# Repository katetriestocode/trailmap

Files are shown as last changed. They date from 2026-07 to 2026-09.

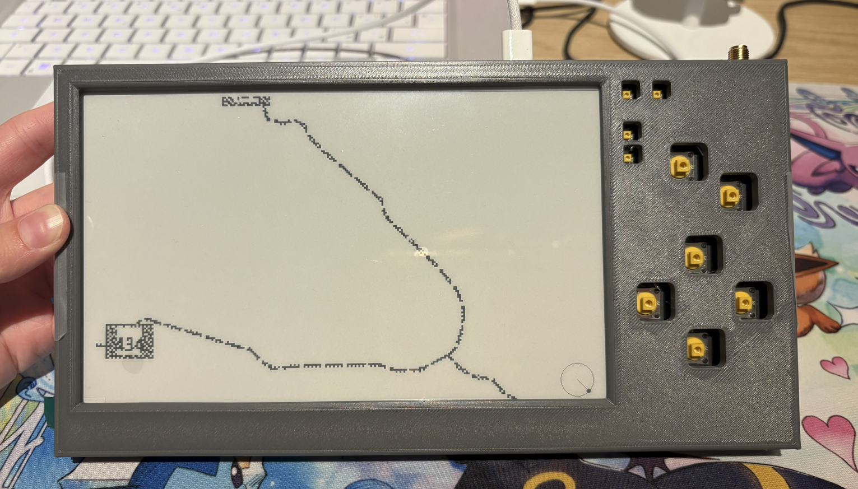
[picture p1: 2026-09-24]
Screenshot 2026-09-24 234755.png

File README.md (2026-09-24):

# trailmap
trailmap is a long lasting, gps enabled, e-ink trail map viewer! equipped with temperature, humidity, magnetometer, altitude and gps, it lets the user choose and follow hiking trails like a map! with a usb-c rechargeable lipo battery, it will provide a long lasting and wifi-scarcity proof solution to digital maps :D

this is the working version! (disclaimer: no antenna as it has not delivered yet, so manual gps coords insertion for now!)



provisional 3d model:

model

pcb:





schematic:

schematic

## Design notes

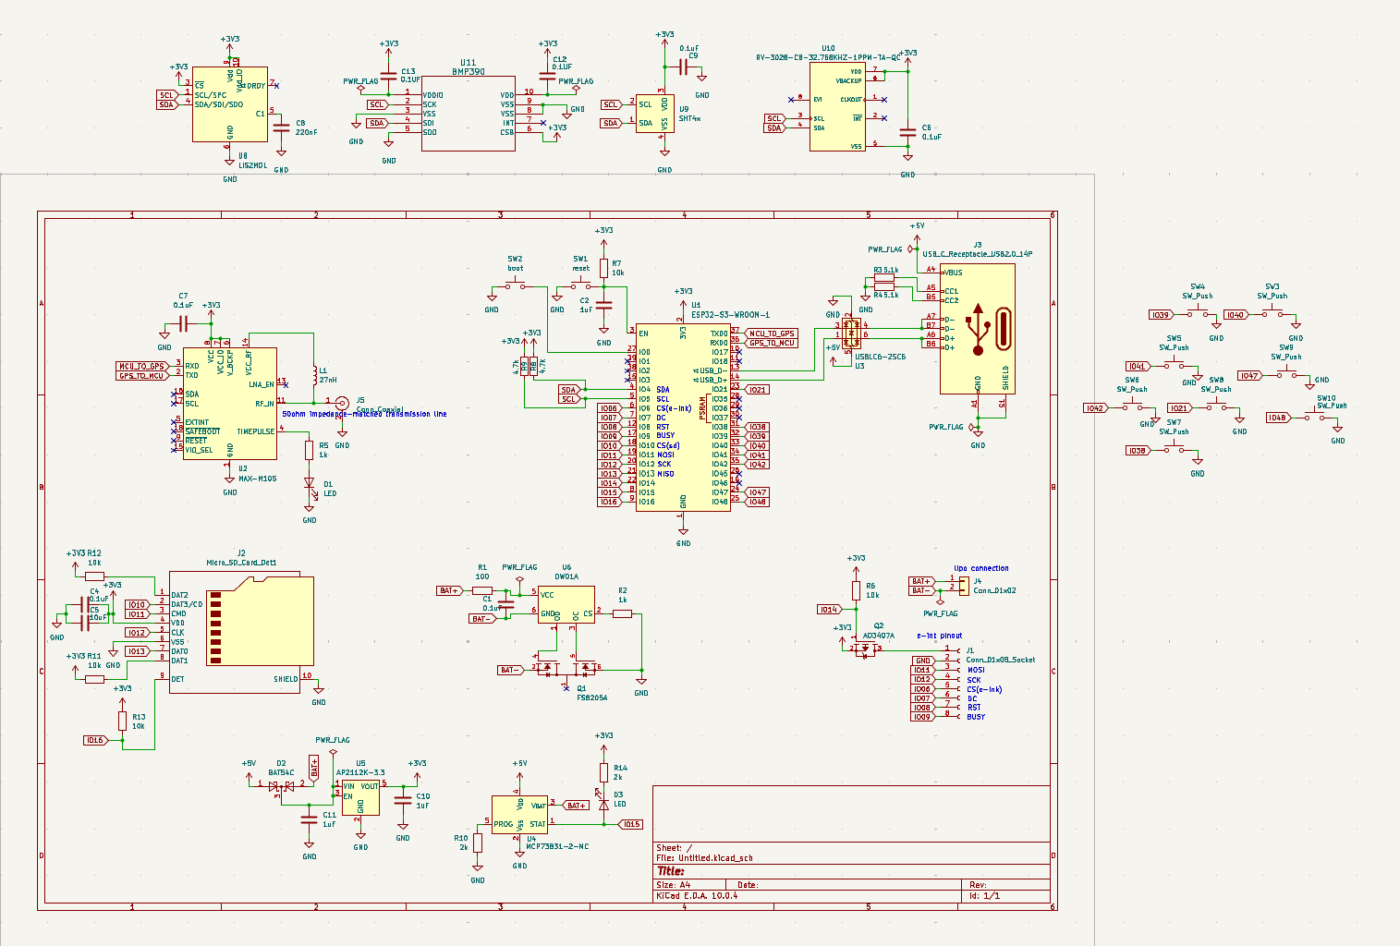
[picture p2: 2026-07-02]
assets/schematic.png

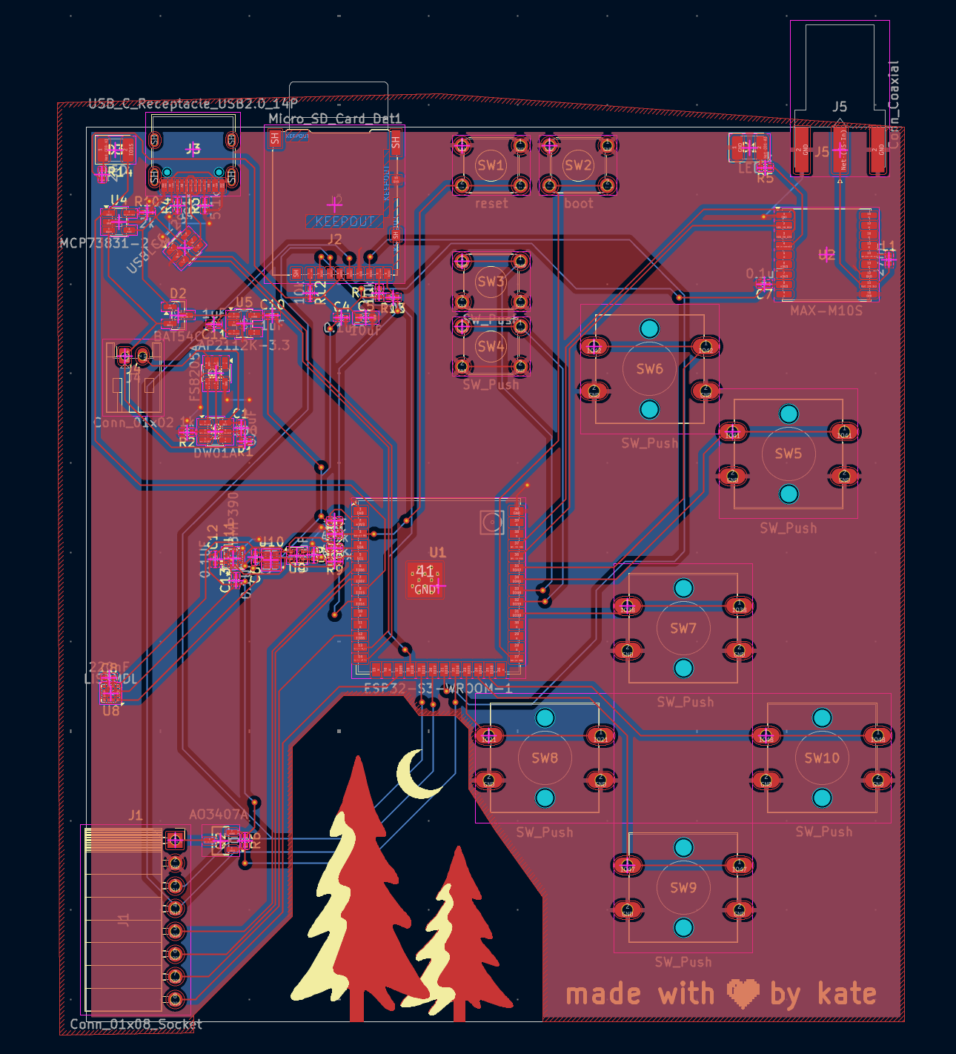
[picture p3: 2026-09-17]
assets/pcb.png

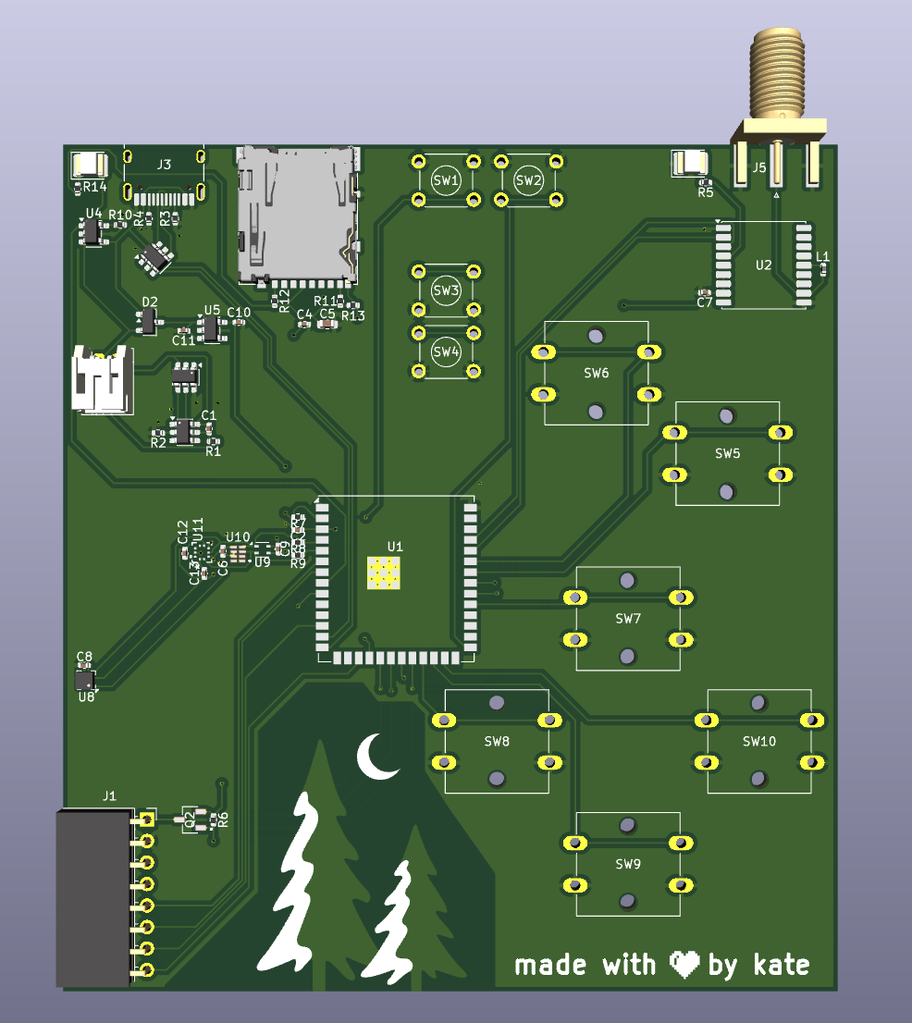
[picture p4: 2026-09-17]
assets/3dpcb.png

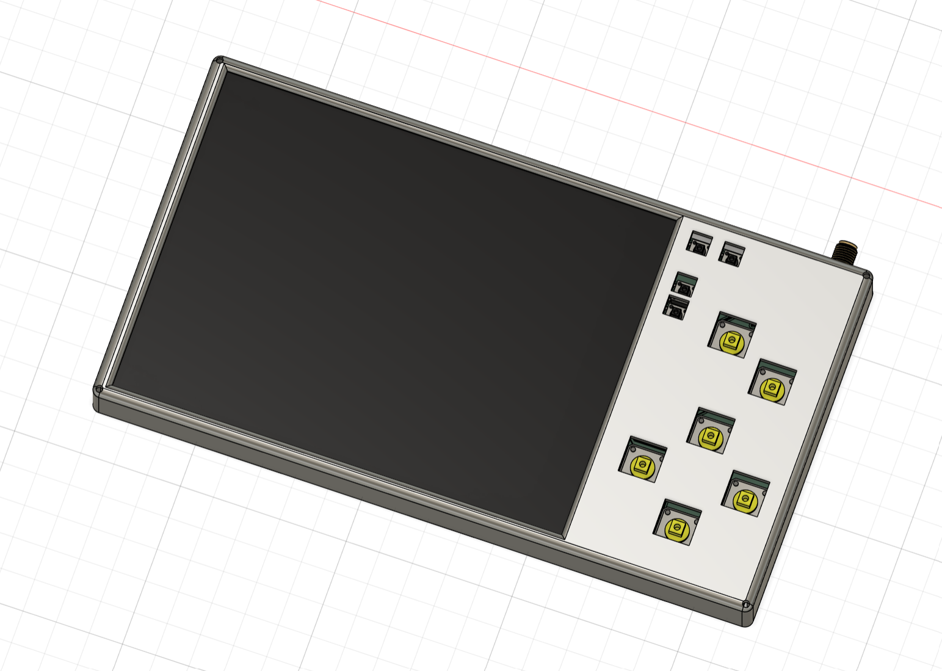
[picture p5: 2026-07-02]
assets/model.png

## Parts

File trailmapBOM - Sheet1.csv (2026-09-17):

item | price | link
PCB | 4$ | JLCPCB
assembly | 139.15$ | JLCPCB
shipping | tba ~10$?
e-ink and adapter | 41$ | https://buy-lcd.com/products/gdey075t7?VariantsId=10628
shipping | 11.42
total: | 196$

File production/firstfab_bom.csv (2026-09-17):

Designator | Footprint | Quantity | Value | LCSC Part #
C1, C12, C13, C14, C4, C7, C9 | 0402 | 7 | 0.1uF
C10, C11, C2 | 0402 | 3 | 1uF
C5 | 0603 | 1 | 10uF
C8 | 0402 | 1 | 220nF
D1, D3 | 1210 | 2 | LED
D2 | SOT-23 | 1 | BAT54C
J1 | PinSocket_1x08_P2.54mm_Horizontal | 1 | Conn_01x08_Socket
J2 | microSD_HC_Hirose_DM3AT-SF-PEJM5 | 1 | Micro_SD_Card_Det1
J3 | USB_C_Receptacle_HRO_TYPE-C-31-M-12 | 1 | USB_C_Receptacle_USB2.0_14P
J4 | JST_PH_S2B-PH-K_1x02_P2.00mm_Horizontal | 1 | Conn_01x02
J5 | SMA_Amphenol_132289_EdgeMount | 1 | Conn_Coaxial
L1 | 0402 | 1 | 27nH
Q1 | SOT-23-6 | 1 | FS8205A
Q2 | SOT95P280X125-3N | 1 | AO3407A
R1 | 0402 | 1 | 100
R10, R14 | 0402 | 2 | 2k
R11, R12, R13, R6, R7 | 0402 | 5 | 10k
R2, R5 | 0402 | 2 | 1k
R3, R4 | 0402 | 2 | 5.1k
R8, R9 | 0402 | 2 | 4.7k
SW1 | SW_TH_Tactile_Omron_B3F-100x | 1 | reset
SW10, SW5, SW6, SW7, SW8, SW9 | SW_SPST_Omron_B3F-40xx | 6 | SW_Push
SW2 | SW_TH_Tactile_Omron_B3F-100x | 1 | boot
SW3, SW4 | SW_TH_Tactile_Omron_B3F-100x | 2 | SW_Push
U1 | ESP32-S3-WROOM-1U | 1 | ESP32-S3-WROOM-1
U11 | 10LGA_2X2X0p75_BOS | 1 | BMP390
U2 | ublox_MAX | 1 | MAX-M10S
U3 | SOT-23-6 | 1 | USBLC6-2SC6
U4 | SOT-23-5 | 1 | MCP73831-2-MC
U5 | SOT-23-5 | 1 | AP2112K-3.3
U6 | SOT-23-6 | 1 | DW01A
U7 | MicroCrystal_C7_SON-8_1.5x3.2mm_P0.9mm | 1 | RV-3028-C7
U8 | LGA-12_2x2mm_P0.5mm | 1 | LIS2MDL
U9 | Sensirion_DFN-4_1.5x1.5mm_P0.8mm_SHT4x_NoCentralPad | 1 | SHT4x

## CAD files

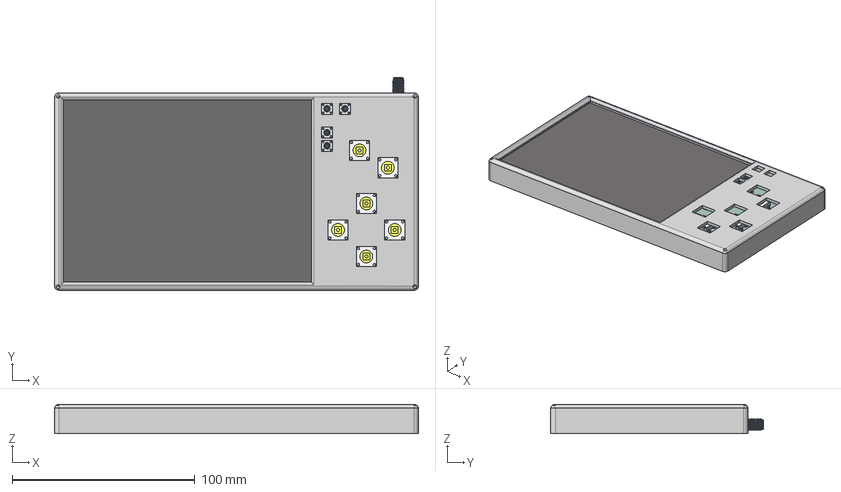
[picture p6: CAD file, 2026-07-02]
3d/caseprototype.step
199.0 x 116.2 x 16.0 mm

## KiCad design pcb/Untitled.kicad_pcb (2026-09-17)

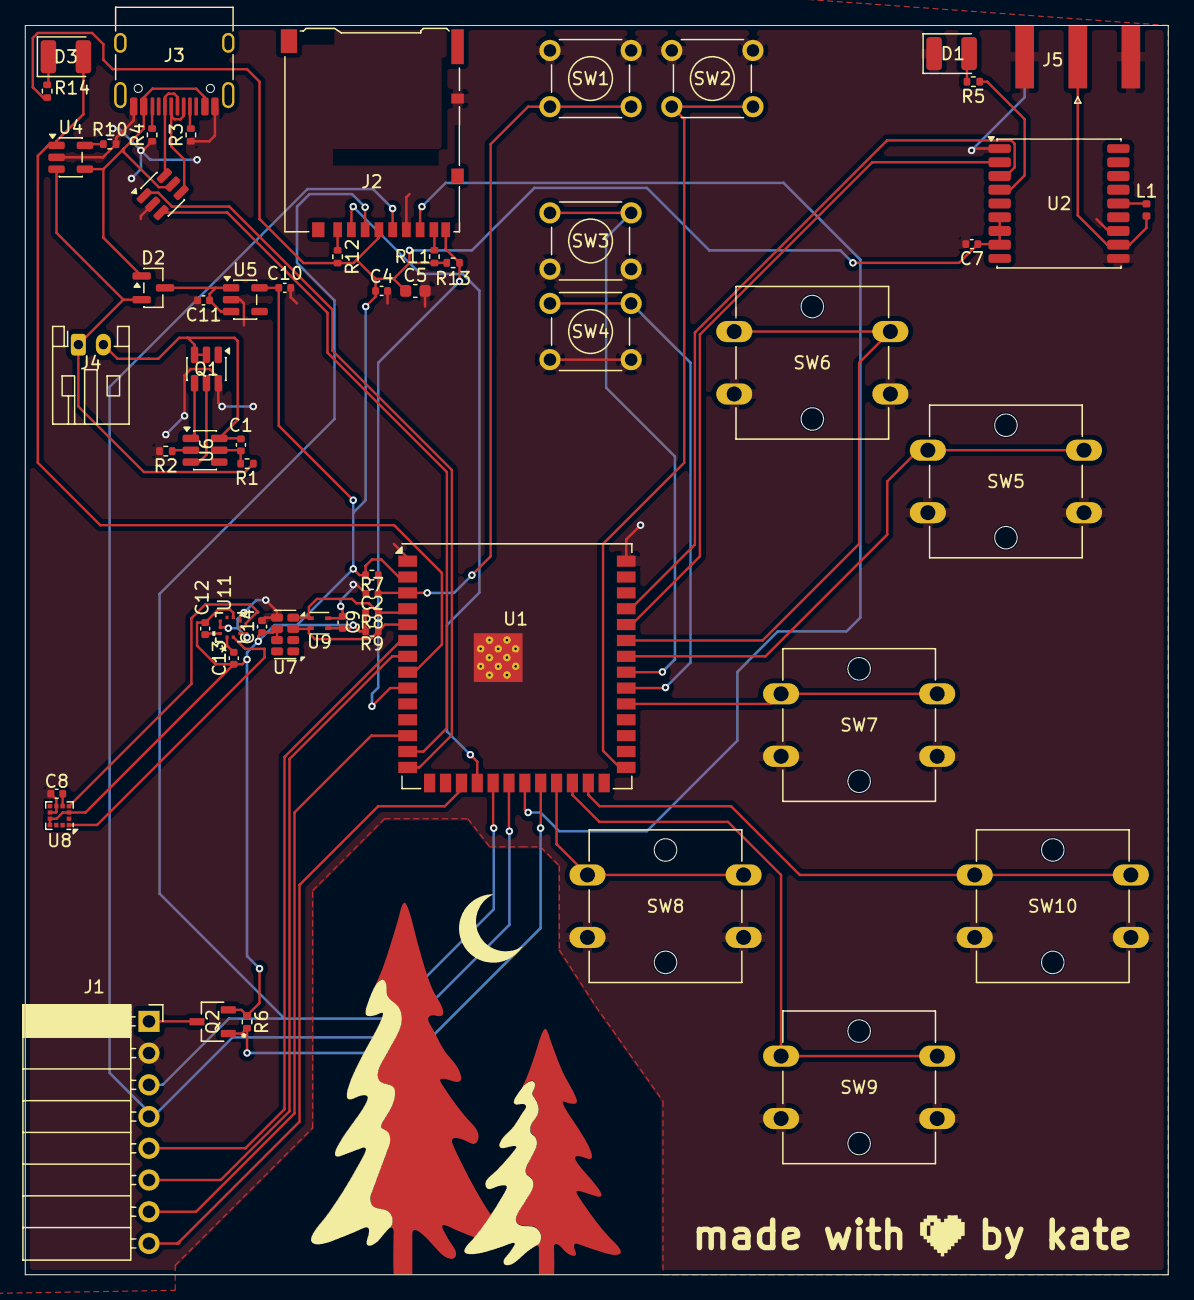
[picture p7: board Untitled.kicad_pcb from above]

Board: 2 copper layers, 91.5 x 100.0 mm, 57 parts (0 on the bottom side), 53 nets.

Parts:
C1, C4, C7, C9, C14: 0.1uF; C_0402_1005Metric
C2, C10, C11: 1uF; C_0402_1005Metric
C5: 10uF; C_0603_1608Metric
C8: 220nF; C_0402_1005Metric
C12, C13: 0.1UF; C_0402_1005Metric
D1, D3: LED; LED_1210_3225Metric
D2: BAT54C; SOT-23
J1: Conn_01x08_Socket; PinSocket_1x08_P2.54mm_Horizontal
J2: Micro_SD_Card_Det1; microSD_HC_Hirose_DM3AT-SF-PEJM5
J3: USB_C_Receptacle_USB2.0_14P; USB_C_Receptacle_HRO_TYPE-C-31-M-12
J4: Conn_01x02; JST_PH_S2B-PH-K_1x02_P2.00mm_Horizontal
J5: Conn_Coaxial; SMA_Amphenol_132289_EdgeMount
L1: 27nH; L_0402_1005Metric
Q1: FS8205A; SOT-23-6
Q2: AO3407A; SOT95P280X125-3N
R1: 100; R_0402_1005Metric
R2, R5: 1k; R_0402_1005Metric
R3, R4: 5.1k; R_0402_1005Metric
R6, R7, R11, R12, R13: 10k; R_0402_1005Metric
R8, R9: 4.7k; R_0402_1005Metric
R10, R14: 2k; R_0402_1005Metric
SW1: reset; SW_TH_Tactile_Omron_B3F-100x
SW2: boot; SW_TH_Tactile_Omron_B3F-100x
SW3, SW4: SW_Push; SW_TH_Tactile_Omron_B3F-100x
SW5, SW6, SW7, SW8, SW9, SW10: SW_Push; SW_SPST_Omron_B3F-40xx
U1: ESP32-S3-WROOM-1; ESP32-S3-WROOM-1U
U2: MAX-M10S; ublox_MAX
U3: USBLC6-2SC6; SOT-23-6
U4: MCP73831-2-MC; SOT-23-5
U5: AP2112K-3.3; SOT-23-5
U6: DW01A; SOT-23-6
U7: RV-3028-C7; MicroCrystal_C7_SON-8_1.5x3.2mm_P0.9mm
U8: LIS2MDL; LGA-12_2x2mm_P0.5mm
U9: SHT4x; Sensirion_DFN-4_1.5x1.5mm_P0.8mm_SHT4x_NoCentralPad
U11: BMP390; 10LGA_2X2X0p75_BOS

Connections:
+3V3: C4.1, C5.1, C7.1, C9.2, C10.1, C12.1, C13.1, C14.1, J2.4 (VDD), Q2.2, R6.1, R7.1, R8.2, R9.2, R11.2, R12.2, R13.1, R14.1, U1.2 (3V3), U2.6 (V_BCKP), U2.7 (VCC_IO), U2.8 (VCC), U5.5 (VOUT), U7.6 (VBACKUP), U7.7 (VDD), U8.3 (~CS), U8.9 (Vdd), U8.10 (Vdd_IO), U9.3 (VDD), U11.6 (CSB)
+5V: D2.1, J3.A4 (VBUS), J3.A9 (VBUS), J3.B4 (VBUS), J3.B9 (VBUS), U3.5 (VBUS), U4.4 (V_{DD})
BAT+: D2.2, J4.1, R1.1, U4.3 (V_{BAT})
BAT-: C1.2, J4.2, Q1.2, Q1.3, U6.6 (GND)
GND: C2.2, C4.2, C5.2, C7.2, C8.2, C9.1, C10.2, C11.2, C14.2, D1.1 (K), J1.2, J2.6 (VSS), J2.10 (SHIELD), J3.A1 (GND), J3.A12 (GND), J3.B1 (GND), J3.B12 (GND), J5.2 (Ext), Q1.6, R2.2, R3.1, R4.1, R10.2, SW1.1, SW2.1, SW3.2, SW4.2, SW5.2, SW6.2, SW7.2, SW8.2, SW9.2, SW10.2, U1.1 (GND), U1.40 (GND), U1.41 (GND), U2.1 (GND), U2.10 (GND), U2.12 (GND), U3.2 (GND), U4.2 (V_{SS}), U5.2 (GND), U7.5 (VSS), U8.6 (GND), U8.8 (GND), U9.4 (VSS), U11.3 (VSS), U11.5 (SDO), U11.8 (VSS), U11.9 (VSS)
GPS_TO_MCU: U1.36 (RXD0), U2.2 (TXD)
IO06: J1.5, U1.6 (IO6)
IO07: J1.6, U1.7 (IO7)
IO08: J1.7, U1.12 (IO8)
IO09: J1.8, U1.17 (IO9)
IO10: J2.2 (DAT3/CD), U1.18 (IO10)
IO11: J1.3, J2.3 (CMD), U1.19 (IO11)
IO12: J1.4, J2.5 (CLK), U1.20 (IO12)
IO13: J2.7 (DAT0), U1.21 (IO13)
IO14: Q2.1, R6.2, U1.22 (IO14)
IO15: D3.2 (A), U1.8 (IO15), U4.1 (STAT)
IO16: J2.9 (DET), R13.2, U1.9 (IO16)
IO21: SW8.1, U1.23 (IO21)
IO38: SW7.1, U1.31 (IO38)
IO39: SW4.1, U1.32 (IO39)
IO40: SW3.1, U1.33 (IO40)
IO41: SW5.1, U1.34 (IO41)
IO42: SW6.1, U1.35 (IO42)
IO47: SW9.1, U1.24 (IO47)
IO48: SW10.1, U1.25 (IO48)
MCU_TO_GPS: U1.37 (TXD0), U2.3 (RXD)
unnamed: D1.2 (A), R5.2
unnamed: D3.1 (K), R14.2
unnamed: J1.1, Q2.3
unnamed: J2.8 (DAT1), R11.1
unnamed: J2.1 (DAT2), R12.1
unnamed: J3.A5 (CC1), R3.2
unnamed: J3.B5 (CC2), R4.2
unnamed: J3.A6 (D+), J3.B6 (D+), U3.6 (I/O1)
unnamed: J3.A7 (D-), J3.B7 (D-), U3.4 (I/O2)
unnamed: J5.1 (In), L1.2, U2.11 (RF_IN)
unnamed: C2.1, R7.2, SW1.2, U1.3 (EN)
unnamed: SW2.2, U1.27 (IO0)
unnamed: U1.14 (USB_D+), U3.1 (I/O1)
unnamed: U1.13 (USB_D-), U3.3 (I/O2)
unnamed: R5.1, U2.4 (TIMEPULSE)
unnamed: L1.1, U2.14 (VCC_RF)
unnamed: R10.1, U4.5 (PROG)
unnamed: C11.1, D2.3, U5.1 (VIN), U5.3 (EN)
unnamed: R2.1, U6.2 (CS)
unnamed: Q1.5, U6.3 (OC)
unnamed: Q1.4, U6.1 (OD)
unnamed: C1.1, R1.2, U6.5 (VCC)
unnamed: C8.1, U8.5 (C1)
unnamed: C12.2, U11.10 (VDD)
unnamed: C13.2, U11.1 (VDDIO)
SCL: R9.1, U1.5 (IO5), U7.3 (SCL), U8.1 (SCL/SPC), U9.2 (SCL), U11.2 (SCK)
SDA: R8.1, U1.4 (IO4), U7.4 (SDA), U8.4 (SDA/SDI/SDO), U9.1 (SDA), U11.4 (SDI)

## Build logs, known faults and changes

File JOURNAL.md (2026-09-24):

# 9/24/2026 7 PM - built!

_Time spent: 5?h_

After ages, i fixed up the code, adapted it to work without gps, made a demo code to test the e-ink, downloaded maps.. etc! anyways it works:


# 7/02/2026 7 PM - bom!

_Time spent: 1h_

I finished the BOM, redone, quite expensive :,) but i couldnt really get it down. I also redid the graphics for my board:


# 7/01/2026 6 PM - 3d model!

_Time spent: 1.5h_

I made a first draft of the 3d model! this is with a provisional eink size, so i might change. tho its a start for submission!


# 7/01/2026 2 PM - pcb finalized!

_Time spent: 2h_

I finished the pcb, and removed all errors but the ones i am ignoring, like pads too small (its the part footprint). 


# 6/30/2026 4 PM - cost reduction!

_Time spent: 1h_

I got the cost down! assembly of only two boards, no standard pieces, and not assembling everything takes it down to around 80$! I also changed the magnetometer to a LIS2MDL, instead of a lis3mdl which i found out is out of production! now i will look at the other pieces i will have to hand solder, as i am unsure how i will solder smd pieces like the esp
{F266392B-B6CA-4F24-A104-2809517627C4}


# 6/28/2026 10 PM - more wiring + first price check!

_Time spent: 1h_

i started wiring other components but the important ones, fixing errors, and establishing a better layout. I checked prices for just boards, and found everything under 100x100mm is so much cheaper than anything slightly above, so i reduced the space to 100mm horizontally and vertically 100mm, which i can easily reduce based on the screen size i will decided. I got a first pcba price estimate from jlcpcb, and it was 250$??? this is cuz theres like more than 100 dollars of various fees because it is standard rather than econ (constraint based on needing the esp32 wroom 1, which isnt in econ :P) i will drastically reduce the price by soldering it myself (maybe with a hot plate?)
(https://lapse.hackclub.com/timelapse/qy0DC-9HV17Z)



# 6/27/2026 7 PM - wiring start!

_Time spent: 2h_

i found out that i need a HAT to connect the e-ink to my board, which is about 8 euros on aliexpress. I then started wiring, being careful to place decouplers near their adjacent part, and wiring the important wires first (eg info parts and battery)
(https://lapse.hackclub.com/timelapse/zSaDSLh_QurV)


# 6/27/2026 1 PM - switches, buttons, e-ink, and layout start!

_Time spent: 2h_

i struggled choosing which buttons to use, but ended up choosing one with an attachment that would allow a custom cap to make the buttons look more professional. I also started laying out the items based on the e-ink layout, considering that the gps should be away from everything else, and that the usb-c and sd card need to be in a convenient position.
(https://lapse.hackclub.com/timelapse/XH70X7rhDU6x)+(https://lapse.hackclub.com/timelapse/bGLBh-pUC-5d)


# 6/26/2026 5 PM - footprint assignment!

_Time spent: 2h_

assigned footprints! i assigned all the various footprints (except buttons) i struggled figuring out what components corresponded to which SOTs :D
(https://lapse.hackclub.com/timelapse/Y9WYruspzZDs)


# 6/26/2026 10 AM - finished schematic!

_Time spent: 3h_

completely finished wiring, with 0 erros now! took ages to find all the needed decoupling and to figure out were pullups were needed, since i am still a beginenr haha. really proud of it so far. i also struggled with pwr_flags since i kept getting erros about them. im gonna start placing the components next!




# 5/21/2026 4 PM - more wiring

_Time spent: 0.5h_

wired the gps module! it was really tricky as i could not find a lot of schematics online, i got it mostly done but had to ask AI how to wire vcc_rf:



i also started wiring the e-ink, and used the ao3407a documentation to wire it :P






# 5/21/2026 8 AM - wiring the battery protection

_Time spent: 1h_

i wired the battery protection, which turned out to be a huge hassle. i was struggling with the documentation until i found this diagram online:



which really helped me wire everything. tho, my 1 pin is floating (together with the 8 since theyre together), and i asked ai what to do, so apparently i should leave a copper 'island' for it in the pcb to act as a heatsink. ill double check this later.

this is what i did, yay!


i also started scheming the usb:



which i also wired the protection, plus the boot and reset switches for the esp :PP





# 5/19/2026 4 PM - found and placed components!

_Time spent: 1h_

so i found the missing symbols and footprints, and loaded everything into kicad. i mapped everything out according to its role:

so it (atm) looks like this:






# 5/12/2026 7 PM - planning and part finding!

_Time spent: 1.5h_

I started by roughly finding all the parts i wanted for the functions!
The functions i plan are:

- [ ] e-ink display
- [ ] live updating map
- [ ] preloaded trail route map
- [ ] live positioning
- [ ] long lasting battery
- [ ] usb-c charging
- [ ] compass
- [ ] altimeter
- [ ] direction pointing
- [ ] clock
- [ ] temperature
- [ ] sensor

Additionally, since this is made for outdoors, i need it to be safe, reliable and durable, so i added all the possible precautions regarding power.



i also started reflecting on the actual screen, but i found that e-ink displays can get really expensive really fast. I provisionally decided on a 5.8" wave-share display, but i need to check regarding partial refresh, as in rapid movements it would be beneficial for it to not repeatedly refresh the whole page.



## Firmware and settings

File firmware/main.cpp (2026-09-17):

#include <Arduino.h>
#include <Wire.h>
#include <SPI.h>
#include <SD.h>
#include <math.h>
#include <HardwareSerial.h>
#include <TinyGPSPlus.h>
#include <Adafruit_Sensor.h>
#include <Adafruit_LIS3MDL.h>
#include <Adafruit_BMP390.h>
#include <Adafruit_SHT4x.h>
#include <GxEPD2_BW.h> 


#define I2C_SDA 4
#define I2C_SCL 5
#define GPS_TX 37
#define GPS_RX 36
#define SD_CS 18
#define EINK_CS 6
#define EINK_DC 7
#define EINK_RST 12
#define EINK_BUSY 17


#define BTN_ZOOM_IN 31
#define BTN_ZOOM_OUT 32
#define BTN_A 47
#define BTN_B 48

#define BTN_UP 41
#define BTN_DOWN 38
#define BTN_LEFT 42
#define BTN_RIGHT 21

HardwareSerial GPSSerial(1);
TinyGPSPlus gps;

Adafruit_LIS3MDL magnetometer;
Adafruit_BMP390 altimeter;
Adafruit_SHT4x sht40;

GxEPD2_BW<x::HEIGHT> display(x(EINK_CS, EINK_DC, EINK_RST, EINK_BUSY));


int currentZoom = 14; 
const int MIN_ZOOM = 10;
const int MAX_ZOOM = 16;


double currentLat = 45.4384;
double currentLon = 10.9916;
float heading = 0.0;
float currentTemp = 0.0;
float currentAlt = 0.0;

bool mapNeedsRefresh = true;


void updateSensors();
void handleButtons();
void drawMapScreen();
void drawBMPFromSD(const char *filename, int16_t x, int16_t y);
void drawCompass(int16_t x, int16_t y, float head);
int long2tilex(double lon, int z);
int lat2tiley(double lat, int z);


void setup() {
  Serial.begin(115200);
  

  Wire.begin(I2C_SDA, I2C_SCL);
  if (!magnetometer.begin_I2C()) Serial.println("LIS3MDL Init Failed!");
  if (!altimeter.begin_I2C()) Serial.println("BMP390 Init Failed!");
  if (!sht40.begin()) Serial.println("SHT40 Init Failed!");


  GPSSerial.begin(9600, SERIAL_8N1, GPS_RX, GPS_TX);


  if (!SD.begin(SD_CS)) Serial.println("SD Card Mount Failed!");


  display.init(115200, true, 2, false); // Init with diagnostic output
  display.setRotation(1); // Landscape
  display.fillScreen(GxEPD_WHITE);
  display.display();


  pinMode(BTN_ZOOM_IN, INPUT_PULLUP);
  pinMode(BTN_ZOOM_OUT, INPUT_PULLUP);
  pinMode(BTN_A, INPUT_PULLUP);
}


void loop() {
  while (GPSSerial.available() > 0) {
    if (gps.encode(GPSSerial.read())) {
      if (gps.location.isUpdated()) {
        currentLat = gps.location.lat();
        currentLon = gps.location.lng();
      }
    }
  }


  updateSensors();


  handleButtons();


  if (mapNeedsRefresh) {
    drawMapScreen();
    mapNeedsRefresh = false;
  }
  
  delay(50);
}


void updateSensors() {
  sensors_event_t event;
  magnetometer.getEvent(&event);
  

  heading = atan2(event.magnetic.y, event.magnetic.x) * 180.0 / M_PI;
  if (heading < 0) heading += 360.0;

  sensors_event_t humidity, temp;
  sht40.getEvent(&humidity, &temp);
  currentTemp = temp.temperature;

  currentAlt = altimeter.readAltitude(1013.25); 
}

void handleButtons() {

  if (digitalRead(BTN_ZOOM_IN) == LOW) {
    if (currentZoom < MAX_ZOOM) {
      currentZoom++;
      mapNeedsRefresh = true;
    }
    delay(300);
  }
  
  if (digitalRead(BTN_ZOOM_OUT) == LOW) {
    if (currentZoom > MIN_ZOOM) {
      currentZoom--;
      mapNeedsRefresh = true;
    }
    delay(300);
  }

  if (digitalRead(BTN_A) == LOW) {
    mapNeedsRefresh = true;
    delay(300);
  }
}


void drawMapScreen() {

  int tileX = long2tilex(currentLon, currentZoom);
  int tileY = lat2tiley(currentLat, currentZoom);


  String filePath = "/" + String(currentZoom) + "/" + String(tileX) + "/" + String(tileY) + ".bmp";
  
  display.setFullWindow();
  display.firstPage();
  do {
    display.fillScreen(GxEPD_WHITE);
    

    drawBMPFromSD(filePath.c_str(), 0, (display.height() - 256) / 2); 


    int uiX = 200;
    display.fillRect(uiX, 0, display.width() - uiX, display.height(), GxEPD_WHITE);
    display.drawRect(uiX, 0, display.width() - uiX, display.height(), GxEPD_BLACK);


    display.setTextColor(GxEPD_BLACK);
    display.setCursor(uiX + 5, 10);
    display.print("Zoom: "); display.print(currentZoom);
    
    display.setCursor(uiX + 5, 30);
    display.print("Alt: "); display.print(currentAlt, 0); display.print("m");
    
    display.setCursor(uiX + 5, 50);
    display.print("Temp: "); display.print(currentTemp, 1); display.print("C");

    // 6. Draw Compass User Indicator
    drawCompass(uiX + 45, 100, heading);

  } while (display.nextPage());
}

void drawCompass(int16_t x, int16_t y, float head) {
  // Draw outer ring
  display.drawCircle(x, y, 15, GxEPD_BLACK);
  

  float rad = (head - 90.0) * (M_PI / 180.0);
  int16_t endX = x + (cos(rad) * 15);
  int16_t endY = y + (sin(rad) * 15);
  
  display.drawLine(x, y, endX, endY, GxEPD_BLACK);
  display.fillCircle(endX, endY, 3, GxEPD_BLACK); // Arrow tip
}


int long2tilex(double lon, int z) { 
  return (int)(floor((lon + 180.0) / 360.0 * pow(2.0, z))); 
}

int lat2tiley(double lat, int z) { 
  return (int)(floor((1.0 - asinh(tan(lat * M_PI/180.0)) / M_PI) / 2.0 * pow(2.0, z))); 
}


void drawBMPFromSD(const char *filename, int16_t x, int16_t y) {

  
  File bmpFile = SD.open(filename, FILE_READ);
  if (!bmpFile) {
    Serial.print("File not found: "); Serial.println(filename);
    display.setCursor(x + 10, y + 10);
    display.print("MAP TILE NOT FOUND");
    display.print(filename);
    return;
  }

  bmpFile.close();
}

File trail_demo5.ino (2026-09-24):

#include <Arduino.h>
#include <SPI.h>
#include <SD.h>
#include <GxEPD2_BW.h>

#define GxEPD2_DRIVER_CLASS GxEPD2_750_GDEY075T7

#define EINK_CS     6
#define EINK_DC     7
#define EINK_RST    8
#define EINK_BUSY   9
#define SD_CS       10
#define SPI_MOSI    11
#define SPI_SCK     12
#define SPI_MISO    13
#define EINK_PWR_EN 14

GxEPD2_BW<GxEPD2_DRIVER_CLASS, GxEPD2_DRIVER_CLASS::HEIGHT> display(
  GxEPD2_DRIVER_CLASS(EINK_CS, EINK_DC, EINK_RST, EINK_BUSY));

const char *TRAIL_BMP     = "/trail.bmp";
const float FIXED_HEADING = 45.0;
const int SCALE = 3;

void drawBMP(const char *filename);
void drawCompass(int16_t cx, int16_t cy, int16_t r, float headingDeg);
uint16_t read16(File &f);
uint32_t read32(File &f);

void setup() {
  Serial.begin(115200);
  delay(200);

  pinMode(EINK_PWR_EN, OUTPUT);
  digitalWrite(EINK_PWR_EN, LOW);
  delay(100);

  SPI.begin(SPI_SCK, SPI_MISO, SPI_MOSI, SD_CS);

  pinMode(EINK_CS, OUTPUT);
  digitalWrite(EINK_CS, HIGH);
  pinMode(SD_CS, OUTPUT);
  digitalWrite(SD_CS, HIGH);

  if (!SD.begin(SD_CS, SPI, 4000000)) {
    Serial.println("SD Card Mount Failed!");
  }

  display.init(115200, true, 2, false);
  display.setRotation(1);

  display.setFullWindow();
  display.firstPage();
  do {
    display.fillScreen(GxEPD_WHITE);
    drawBMP(TRAIL_BMP);
    drawCompass(display.width() - 40, 40, 25, FIXED_HEADING);
  } while (display.nextPage());

  Serial.println("Demo screen drawn.");
}

void loop() {
}

void drawCompass(int16_t cx, int16_t cy, int16_t r, float headingDeg) {
  display.drawCircle(cx, cy, r, GxEPD_BLACK);

  float rad  = (headingDeg - 90.0) * (PI / 180.0);
  int16_t ex = cx + (int16_t)(cos(rad) * r);
  int16_t ey = cy + (int16_t)(sin(rad) * r);

  display.drawLine(cx, cy, ex, ey, GxEPD_BLACK);
  display.fillCircle(ex, ey, 3, GxEPD_BLACK);

  display.setCursor(cx - 3, cy - r - 10);
  display.print("N");
}

uint16_t read16(File &f) {
  uint16_t v;
  ((uint8_t *)&v)[0] = f.read();
  ((uint8_t *)&v)[1] = f.read();
  return v;
}

uint32_t read32(File &f) {
  uint32_t v;
  ((uint8_t *)&v)[0] = f.read();
  ((uint8_t *)&v)[1] = f.read();
  ((uint8_t *)&v)[2] = f.read();
  ((uint8_t *)&v)[3] = f.read();
  return v;
}

void drawBMP(const char *filename) {
  File bmpFile = SD.open(filename, FILE_READ);
  if (!bmpFile) {
    Serial.print("File not found: ");
    Serial.println(filename);
    display.setCursor(5, 15);
    display.print("BMP NOT FOUND");
    return;
  }

  if (read16(bmpFile) != 0x4D42) {
    Serial.println("Not a valid BMP file");
    display.setCursor(5, 15);
    display.print("NOT A BMP FILE");
    bmpFile.close();
    return;
  }

  read32(bmpFile);
  read32(bmpFile);
  uint32_t dataOffset = read32(bmpFile);
  uint32_t headerSize = read32(bmpFile);
  int32_t bmpWidth   = (int32_t)read32(bmpFile);
  int32_t bmpHeight  = (int32_t)read32(bmpFile);
  read16(bmpFile);
  uint16_t bitDepth  = read16(bmpFile);
  uint32_t compression = read32(bmpFile);

  Serial.print("BMP: "); Serial.print(bmpWidth); Serial.print("x"); Serial.print(bmpHeight);
  Serial.print(", "); Serial.print(bitDepth); Serial.println("-bit");

  if (compression != 0) {
    Serial.println("Compressed BMPs are not supported - re-export as uncompressed.");
    display.setCursor(5, 15);
    display.print("BMP IS COMPRESSED");
    bmpFile.close();
    return;
  }
  if (bitDepth != 1 && bitDepth != 4 && bitDepth != 8 && bitDepth != 24) {
    Serial.print("Unsupported BMP bit depth: ");
    Serial.println(bitDepth);
    display.setCursor(5, 15);
    display.print("UNSUPPORTED: ");
    display.print(bitDepth);
    display.print("-BIT BMP");
    bmpFile.close();
    return;
  }

  bool paletteBlack[256];
  if (bitDepth <= 8) {
    uint32_t paletteStart = 14 + headerSize;
    uint32_t paletteBytes = dataOffset - paletteStart;
    uint32_t numColors = paletteBytes / 4;
    if (numColors > 256) numColors = 256;

    bmpFile.seek(paletteStart);
    for (uint32_t i = 0; i < numColors; i++) {
      uint8_t b = bmpFile.read();
      uint8_t g = bmpFile.read();
      uint8_t r = bmpFile.read();
      bmpFile.read();
      paletteBlack[i] = ((r + g + b) / 3) < 128;
    }
  }

  bool topDown = false;
  if (bmpHeight < 0) {
    bmpHeight = -bmpHeight;
    topDown = true;
  }

  int32_t outW = bmpHeight * SCALE;  
  int32_t outH = bmpWidth  * SCALE;

  int16_t x = (display.width()  - outW) / 2;
  int16_t y = (display.height() - outH) / 2;
  if (x < 0) x = 0;
  if (y < 0) y = 0;

  uint32_t rowSize = ((bmpWidth * bitDepth + 31) / 32) * 4;
  uint8_t *rowBuf = (uint8_t *)malloc(rowSize);
  if (!rowBuf) {
    Serial.println("Not enough RAM to read this BMP row.");
    display.setCursor(5, 15);
    display.print("OUT OF MEMORY");
    bmpFile.close();
    return;
  }

  for (int32_t row = 0; row < bmpHeight; row++) {
    int32_t srcRow = topDown ? row : (bmpHeight - 1 - row);
    bmpFile.seek(dataOffset + (uint32_t)srcRow * rowSize);
    bmpFile.read(rowBuf, rowSize);

    for (int32_t col = 0; col < bmpWidth; col++) {
      bool black;

      if (bitDepth == 1) {
        uint8_t byteVal = rowBuf[col / 8];
        uint8_t idx = (byteVal >> (7 - (col % 8))) & 0x01;
        black = paletteBlack[idx];
      } else if (bitDepth == 4) {
        uint8_t byteVal = rowBuf[col / 2];
        uint8_t idx = (col % 2 == 0) ? (byteVal >> 4) : (byteVal & 0x0F);
        black = paletteBlack[idx];
      } else if (bitDepth == 8) {
        black = paletteBlack[rowBuf[col]];
      } else {
        uint8_t b = rowBuf[col * 3 + 0];
        uint8_t g = rowBuf[col * 3 + 1];
        uint8_t r = rowBuf[col * 3 + 2];
        black = ((r + g + b) / 3) < 128;
      }

      if (black) {
        int16_t dx = x + row * SCALE;
        int16_t dy = y + (bmpWidth - 1 - col) * SCALE;
        display.fillRect(dx, dy, SCALE, SCALE, GxEPD_BLACK);
      }
    }
  }

  free(rowBuf);
  bmpFile.close();
}

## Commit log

2026-07-04 Update trailmapBOM
    [trailmapBOM - Sheet1.csv]
2026-07-05 new bom
    [new_bom.csv, Untitled.kicad_pcb, new_designators.csv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]
